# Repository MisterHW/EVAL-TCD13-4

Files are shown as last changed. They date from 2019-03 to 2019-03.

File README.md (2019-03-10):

# EVAL-TCD13-4
A 13 dB dual directional coupler designed with two Mini-Circuits TCD13-4+ for 5 to 1000 MHz.
Designed with KiCAD and tested in hardware.

## board view

The coupler is implemented using common Tg150 FR4 in 1.6 mm thickness and has four SMA edge ports.
50 Ohm traces are implemented as fenced stripline and tapered to connect to the transformer pads. 

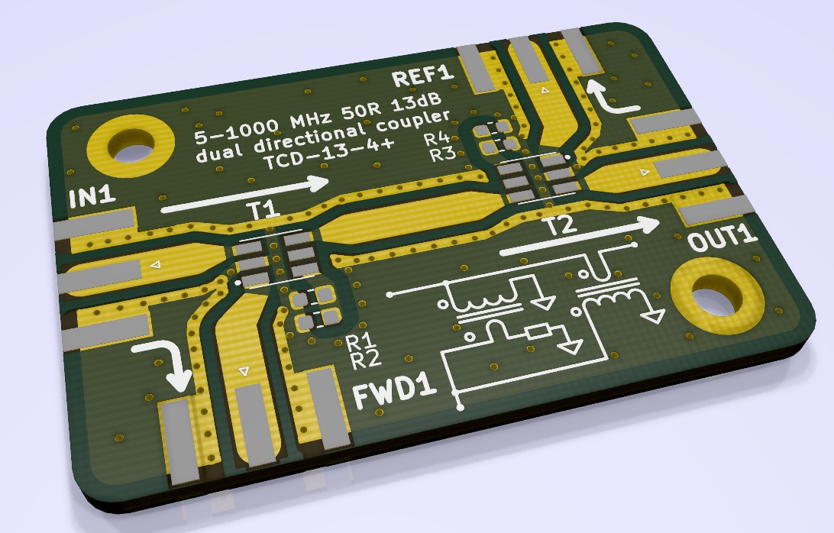
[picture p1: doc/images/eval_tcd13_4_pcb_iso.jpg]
pcb image


the silkscreen showcases one of two 0° directional couplers, the kind which is detailed in [the excellent article by Michael G. Ellis](http://www.members.tripod.com/michaelgellis/direct.html)

## design

The design of the trace geometry to achieve 50 Ohm impedance was done using [atlc2](http://www.hdtvprimer.com/kq6qv/atlc2.html).
Via fencing may be a bit academic in this case but was implemented for educational purposes and because it is not reflected in the cost for the PCB.

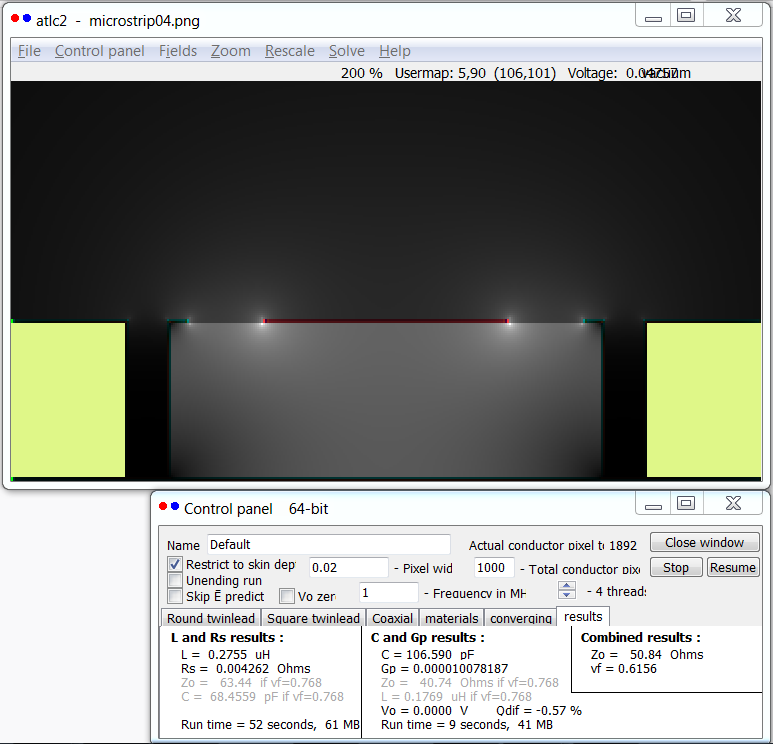
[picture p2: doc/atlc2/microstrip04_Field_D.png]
atlc2 stripline design


## test results

One board was assembled and tested over 0.5 - 1800 MHz using an HP 4396B network analyzer. Coupling was found to be -12.6 dB at 900 MHz, with good flatness over the targeted frequency range.
Insertion loss and directivity are in agreement with typical values given in the [TCD13-4+](https://www.minicircuits.com/WebStore/dashboard.html?model=TCD-13-4%2B) characterization from Mini-Ciruits.

Here's what the assembled PCB looks like in action:
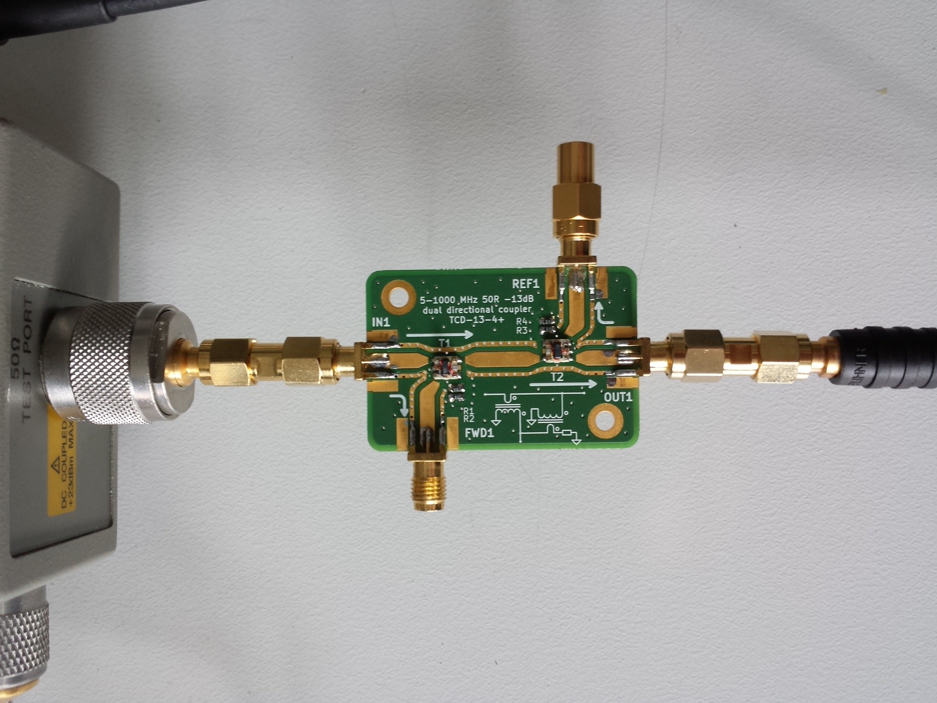
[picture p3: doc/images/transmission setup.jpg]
test setup

(Note: the PCB in the setup shows the wrong coupler circuit. This has been fixed in the project files. The rendering above depicts the correct circuit.)

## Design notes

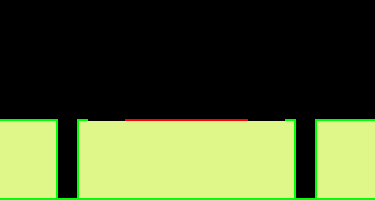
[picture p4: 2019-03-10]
doc/atlc2/microstrip04.png

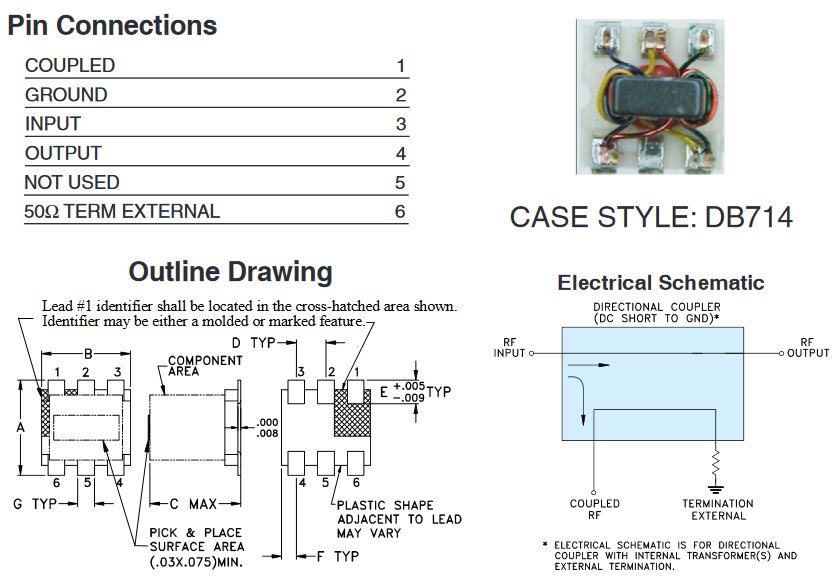
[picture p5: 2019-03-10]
doc/images/tcd13-4-ds.jpg

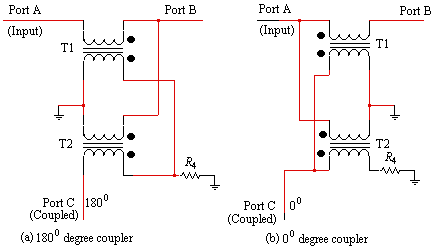
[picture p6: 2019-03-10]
doc/images/wideband_coupler_types.gif

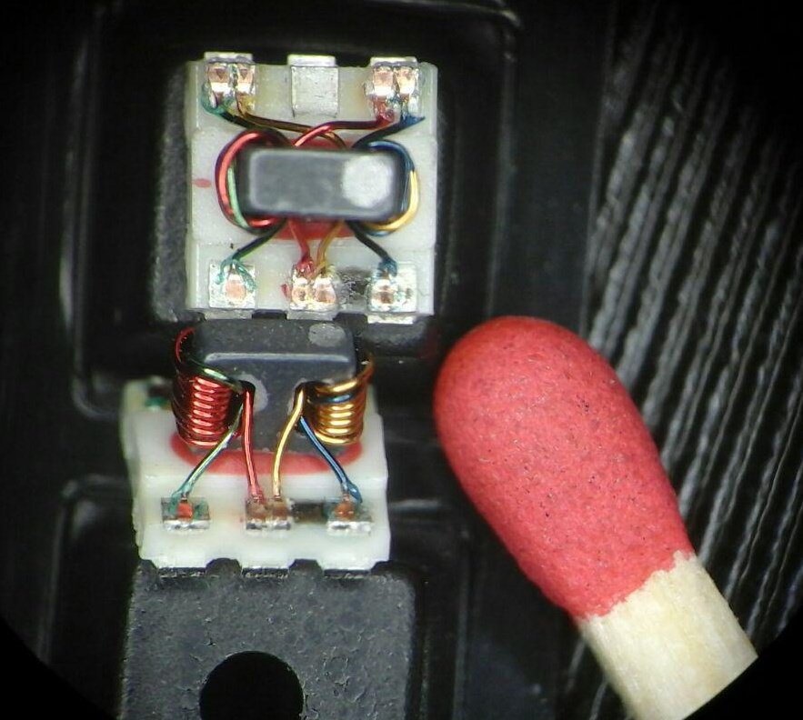
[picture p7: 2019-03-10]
doc/images/TCD13-4 match.jpg

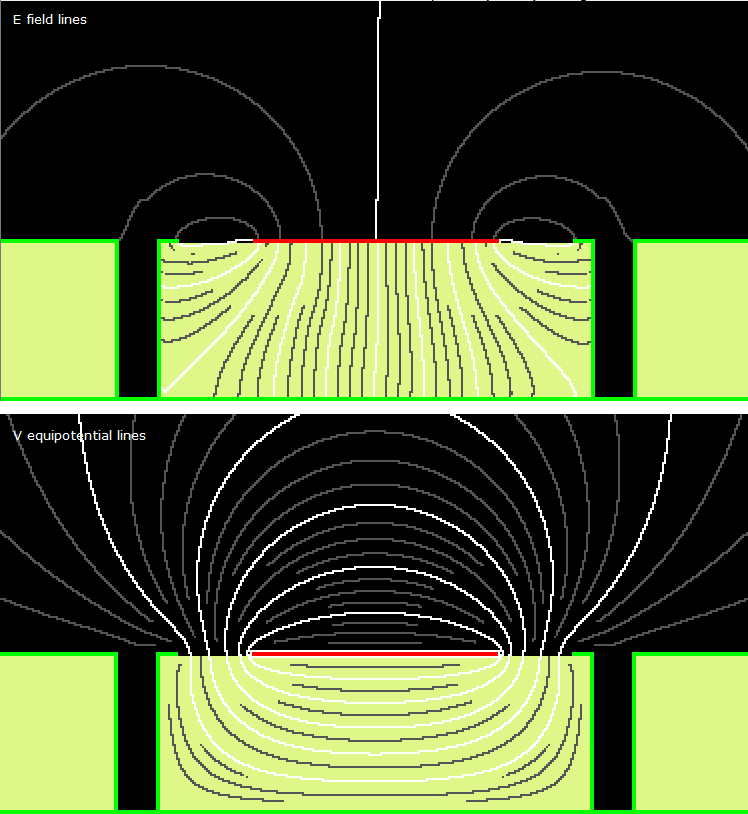
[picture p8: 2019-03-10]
doc/atlc2/microstrip04_fields.png

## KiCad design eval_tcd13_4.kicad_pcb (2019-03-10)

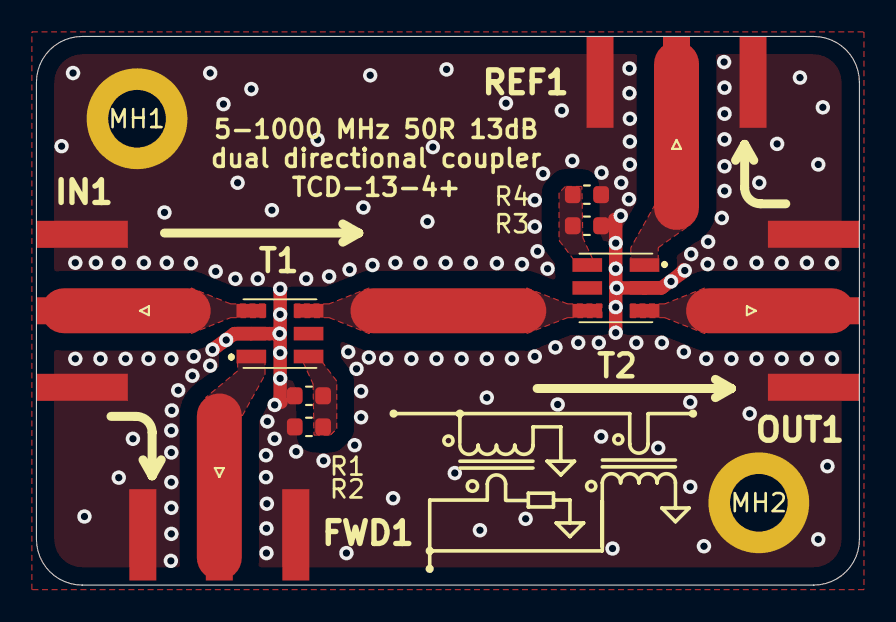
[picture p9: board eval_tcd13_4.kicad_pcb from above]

Board: 2 copper layers, 45.7 x 30.5 mm, 12 parts (0 on the bottom side), 7 nets.

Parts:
FWD1: Conn_Coaxial; SMA_Amphenol_132289_EdgeMount
IN1: Conn_Coaxial; SMA_Amphenol_132289_EdgeMount
MH1, MH2: MountingHole_Pad; MountingHole_3.2mm_M3_DIN965_Pad
OUT1: Conn_Coaxial; SMA_Amphenol_132289_EdgeMount
R1, R2, R3, R4: 100; R_0603_1608Metric
REF1: Conn_Coaxial; SMA_Amphenol_132289_EdgeMount
T1, T2: TCD-13-4+; TCD134

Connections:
GND: FWD1.2, IN1.2, MH1.1, MH2.1, OUT1.2, R1.1, R2.1, R3.1, R4.1, REF1.2, T1.2, T2.2
unnamed: FWD1.1, T1.1
unnamed: IN1.1, T1.3
unnamed: OUT1.1, T2.3
unnamed: R1.2, R2.2, R3.2, R4.2, T1.6
unnamed: REF1.1, T2.1
unnamed: T1.4, T2.4
